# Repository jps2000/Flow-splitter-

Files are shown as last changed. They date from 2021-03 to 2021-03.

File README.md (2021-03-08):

# Flow partition device
Flow splitter for equine spirometry

The device distribute air flow into 4 branches having equal resistance. Hence the use of standard spirometry sensors for adults can be inserted in every branch and be used for horse spirometry. Measurement can be done on one sensor. Volume readings have to be multiplied by 4, Compliance readings have to be divided by 4.

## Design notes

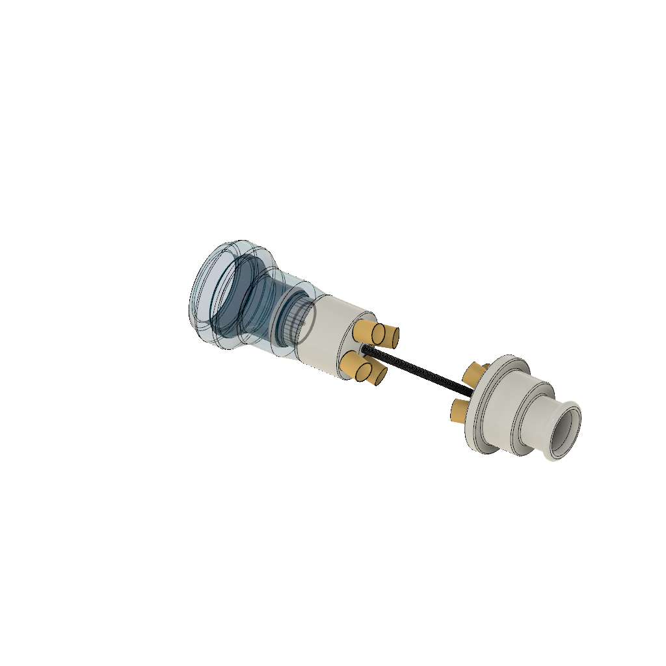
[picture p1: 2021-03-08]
FPD.png

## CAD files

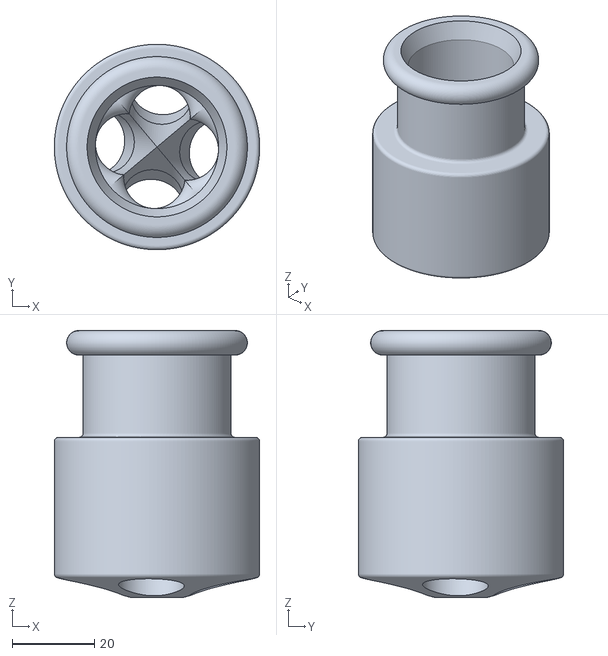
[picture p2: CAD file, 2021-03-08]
FDP2.stl
50.0 x 50.0 x 65.0

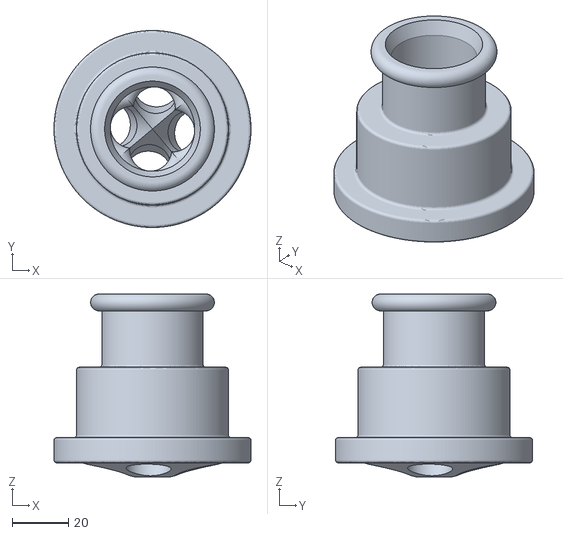
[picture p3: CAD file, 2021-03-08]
FPD1.stl
70.0 x 70.0 x 65.0

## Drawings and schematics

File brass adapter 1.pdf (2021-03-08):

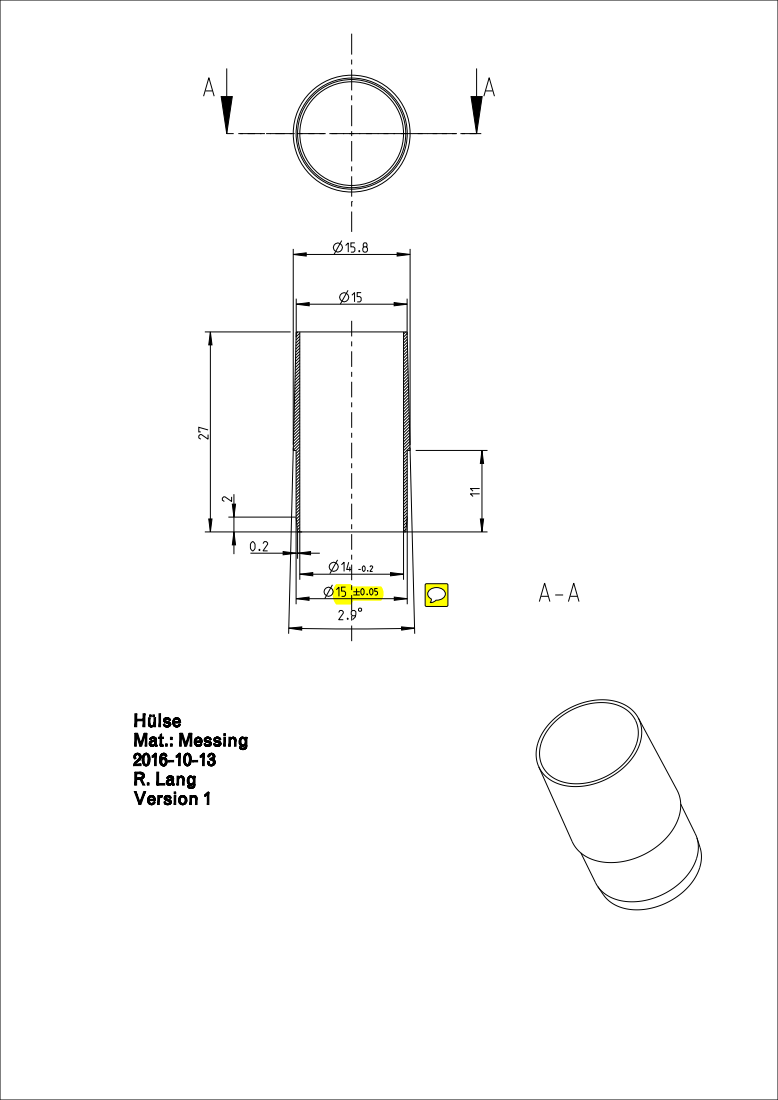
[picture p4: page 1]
Hülse Mat.: Messing 2016-10-13 R. Lang Version 1

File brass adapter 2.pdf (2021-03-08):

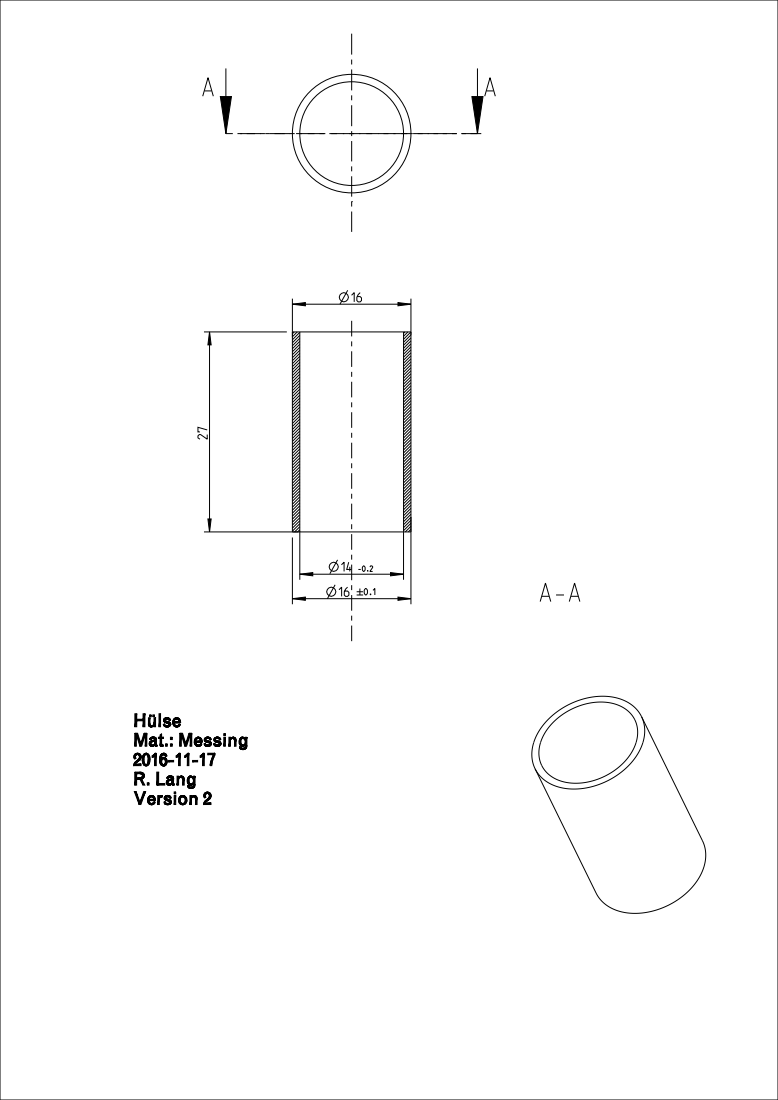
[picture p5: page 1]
Hülse Mat.: Messing 2016-11-17 R. Lang Version 2

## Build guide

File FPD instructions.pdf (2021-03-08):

Materials for flow splitter © Vetmedunui Vienna | V1_1 JPS 2019‐01‐23

Main parts

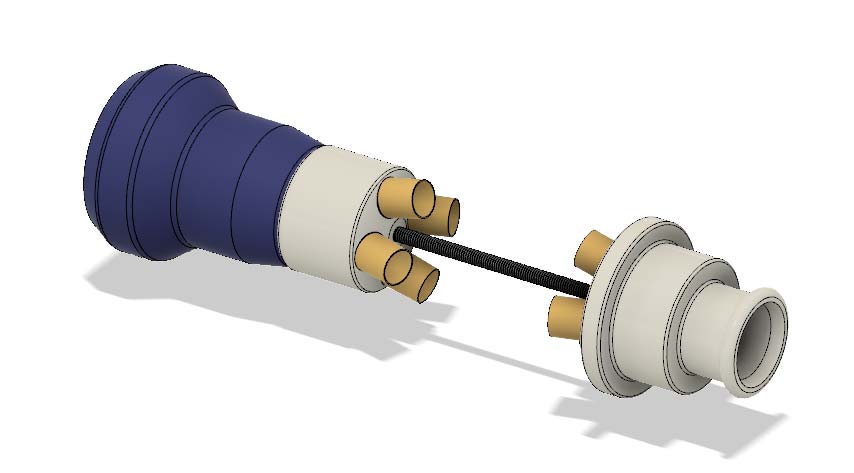
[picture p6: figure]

Flow splitter 1, flow splitter 2

3D printed . Prederred Technology SLS, material PA2200. + Surface sealing

For example: www.rapidobject.com (Leipzig Germany)

Alternative: FDM, material PLA may work as well; avoid support

Cut M6 threads in the centre for the threaded rod

Brass connectors:

Raw material: brass tube 16mm x 1mm x ~ 500mm

Make 4 pieces each (brass adapter1.pdf, brass adapter 2.pdf)

Others:

Silicon tube 15mm x 21mm x ~ 1m ; cut 4 pieces to appropriate length

Threaded rod M6 Stainless steel L = 200mm, 1 piece

washer M6 Stainless steel | 2 pieces
Safety nut M6 Stainless steel | 2 pieces

1 Bell adapter from broken ETT (remove silicon, cut to diameter
